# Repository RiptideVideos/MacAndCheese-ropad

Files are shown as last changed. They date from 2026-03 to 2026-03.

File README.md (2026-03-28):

# MacAndCheese-ropad

The MacAndCheese-ropad is a 4x4 macropad running on a Xiao RP2040. All 16 of the macropad buttons are fully customizable with the QMK firmware or other firmware that the RP2040 supports. 

The MacAndCheese-ropad is intended to be used for daily tasks like copying, pasting, taking a screenshot, ect. THe buttons can also be used as extra function buttons (up to 8 on MacOS and 12 on Windows). Using more adanced software, the buttons could be tied to app specific functions or really anything that can be run on a computer.

> Learn more about button use for QMK here: https://docs.qmk.fm/keycodes_basic

I built the MacAndCheese-ropad because I thought it would be a fun but not to hard challage, it has been just as expected. While some of it was smooth sailing a lot was feeling like I was in the dark on many things, however I was able to pull through and continue the project. I hope this macropad makes me more productive and proud to have somthing I worked hard on be usful to me.

## The Design:

The design features 16 square keys layed out in a 4x4 grid.
- The keys are Cherry MX switches.
- There is a empty space right of the keys which holds the Xiao RP2040.

> Onshape File: https://cad.onshape.com/documents/c366476147c6a16a111f20a0/w/74e1df7ada6eec6626497acf/e/e85a476c3b104135c352d93f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
 
Screenshot 2026-03-14 at 8 59 48 AM

## The PCB:

The PCB uses a matrix to support all 16 keys, a photo of the PCB in KiCad is below:

Screenshot 2026-03-20 at 3 21 23 PM

## The Firmware

The MacAndCheese-ropad uses the QMK firmware to give the keys uses, currentally the firmware is set up with 2 layers of keys. (The exact set up is in the repo).

## Bill of Materials

| Item | Qty | Source | Price | Unit Price | Provided by Hackpad? |
|---|-----|---|---|---|---|
| Seeed XIAO RP2040 | 1 | https://www.seeedstudio.com/XIAO-RP2040-v1-0-p-5026.html | $3.99 | $3.99 | Yes |
| 1N4148 Diodes | 16 | https://www.amazon.com/dp/B06XB1R2NK | ~$0.05	| $4.99 | Yes |
| Cherry MX Switches | 16 | https://www.amazon.com/Cherry-Switch-Mechanical-Keyboard-Switches/ | $0.55	| $19.99 | Yes |
| DSA Keycaps | 16 | https://www.amazon.com/Mechkeeb-Profile-Switches-Keyboard-Replacement/dp/B0BWDQ3NKK | ~$0.37 | $8.99 | Yes |
| PCB | 1 | JLC PCB | $4-7 | $4-7 | Via Grant |
| Soldering Iron | 1 | https://pine64.com/product/pinecil-smart-mini-portable-soldering-iron/ | $25.99 | $25.99 | Via Grant |

> Notes on BOM:
> The PCB price changes based on color, settings and deliver option.
> The exact Soldering Iron isn't needed for this project and you could get others online.

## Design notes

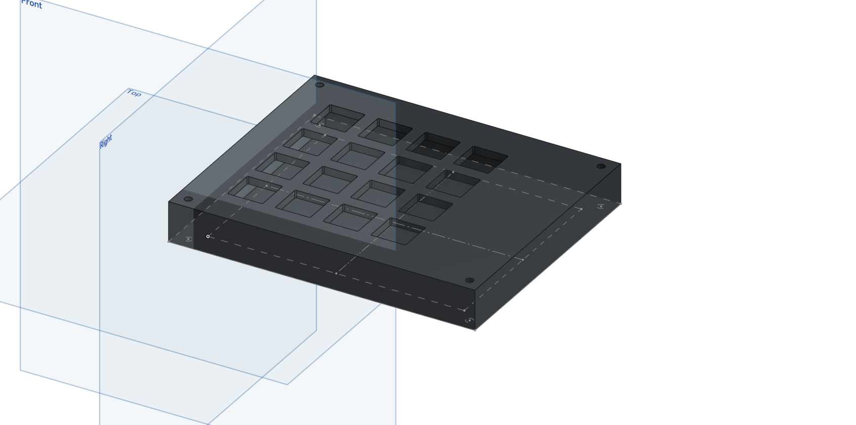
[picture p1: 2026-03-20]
Images/caddesign.png

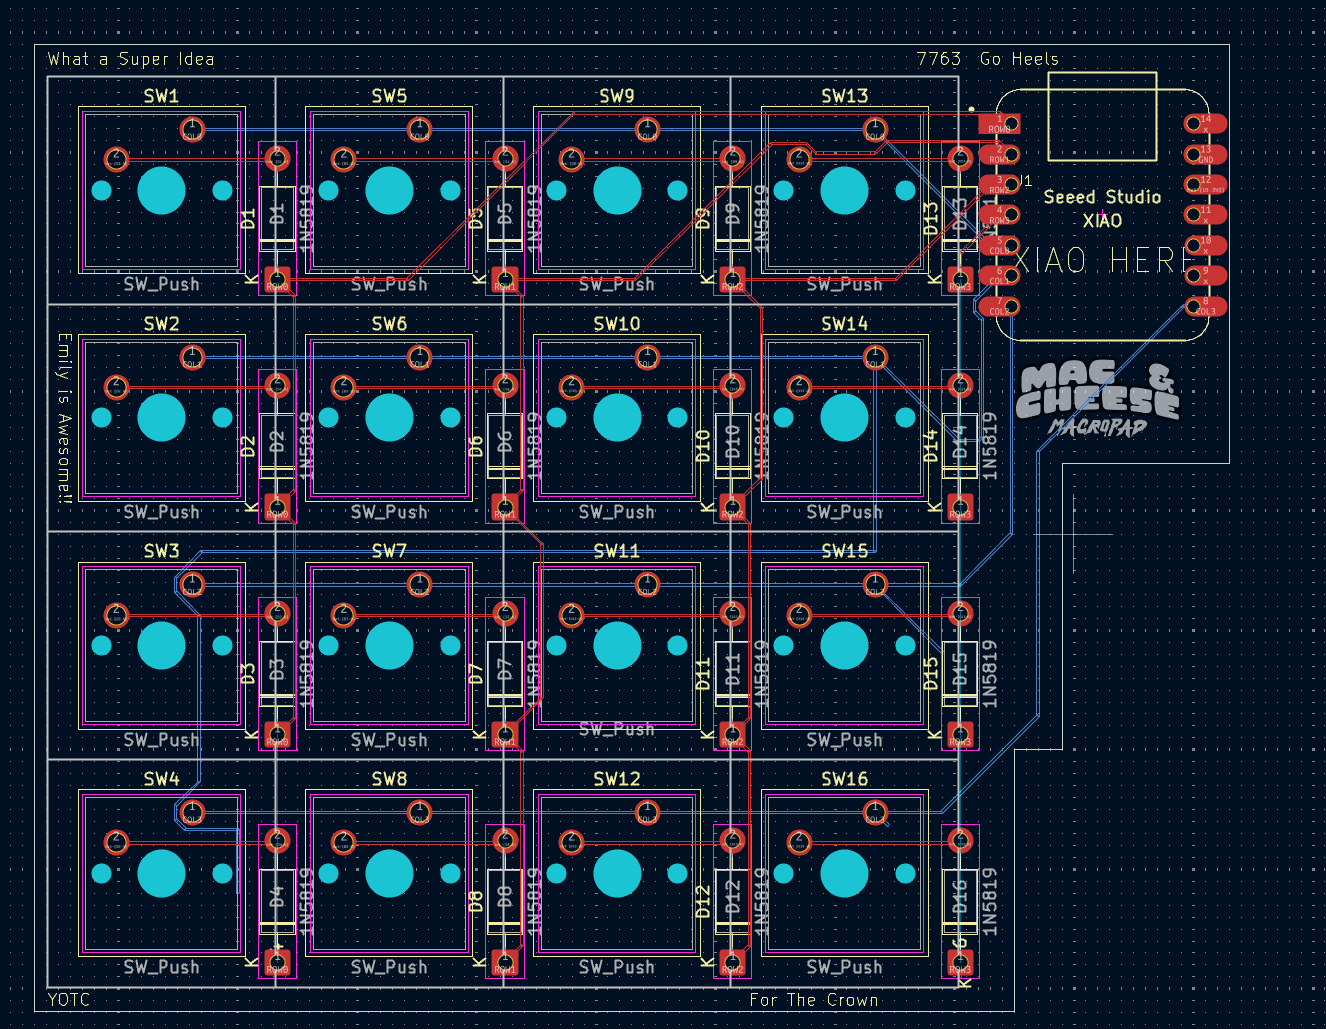
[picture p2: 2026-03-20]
Images/pcb.png

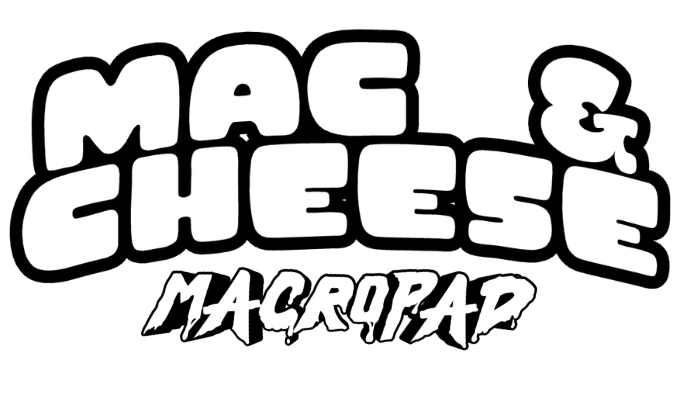
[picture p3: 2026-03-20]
Images/Mac%Cheese-ropad.png

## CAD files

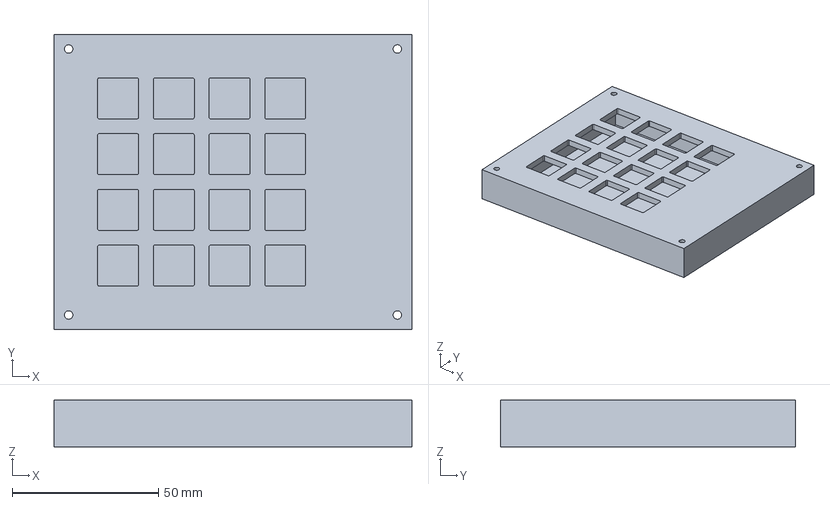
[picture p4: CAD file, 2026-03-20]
3D Files/4x4 PCB 1.step
122.4 x 101.0 x 16.0 mm

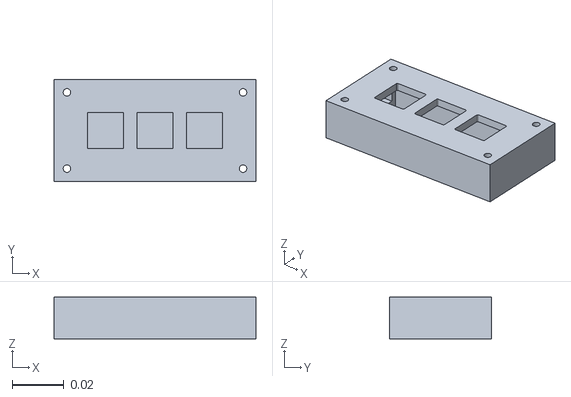
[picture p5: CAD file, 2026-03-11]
3D Files/3x1 PCB.stl
0.0778 x 0.0394 x 0.016

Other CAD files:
3D Files/4x4 PCB 1.stl

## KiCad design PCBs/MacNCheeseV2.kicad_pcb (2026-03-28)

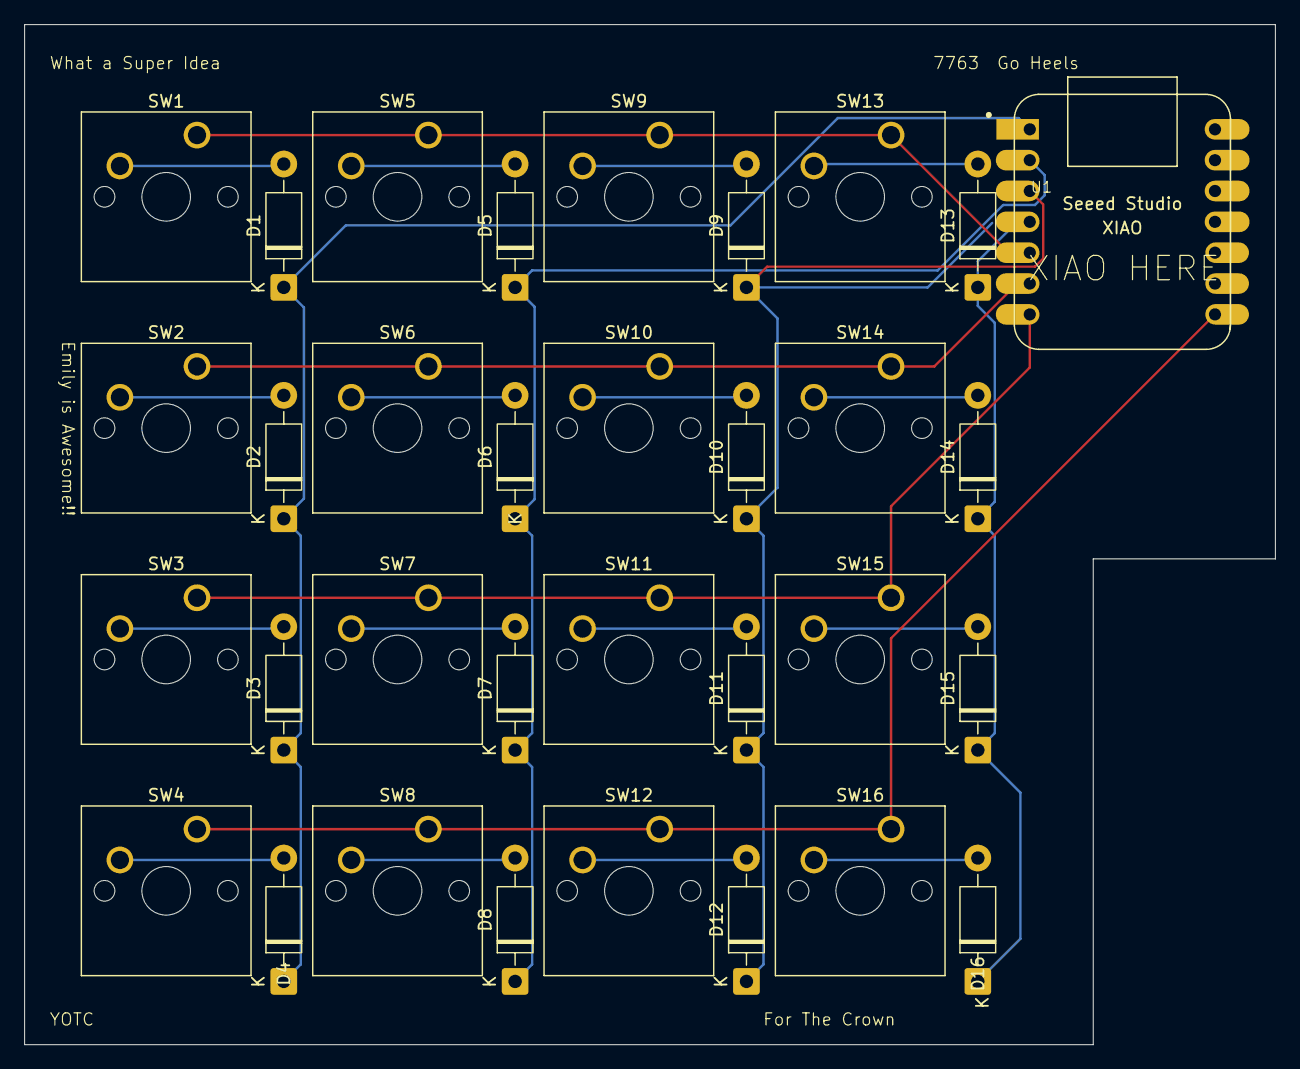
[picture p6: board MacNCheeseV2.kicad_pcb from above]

Board: 2 copper layers, 103.0 x 84.0 mm, 33 parts (0 on the bottom side), 24 nets.

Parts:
D1, D2, D3, D4, D5, D6, D7, D8, D9, D10, D11, D12, D13, D14, D15, D16: 1N5819; D_DO-41_SOD81_P10.16mm_Horizontal
SW1, SW2, SW3, SW4, SW5, SW6, SW7, SW8, SW9, SW10, SW11, SW12, SW13, SW14, SW15, SW16: SW_Push; SW_Cherry_MX_1.00u_PCB
U1: MOUDLE-SEEEDUINO-XIAO; XIAO-Generic-Hybrid-14P-2.54-21X17.8MM

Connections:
/COL0: SW1.1, SW5.1, SW9.1, SW13.1, U1.5 (PA8_A4_D4_SDA)
/COL1: SW2.1, SW6.1, SW10.1, SW14.1, U1.6 (PA9_A5_D5_SCL)
/COL2: SW3.1, SW7.1, SW11.1, SW15.1, U1.7 (PB08_A6_D6_TX)
/COL3: SW4.1, SW8.1, SW12.1, SW16.1, U1.8 (PB09_A7_D7_RX)
/ROW0: D1.1 (K), D2.1 (K), D3.1 (K), D4.1 (K), U1.1 (PA02_A0_D0)
/ROW1: D5.1 (K), D6.1 (K), D7.1 (K), D8.1 (K), U1.2 (PA4_A1_D1)
/ROW2: D9.1 (K), D10.1 (K), D11.1 (K), D12.1 (K), U1.3 (PA10_A2_D2)
/ROW3: D13.1 (K), D14.1 (K), D15.1 (K), D16.1 (K), U1.4 (PA11_A3_D3)
unnamed: D1.2 (A), SW1.2
unnamed: D2.2 (A), SW2.2
unnamed: D3.2 (A), SW3.2
unnamed: D4.2 (A), SW4.2
unnamed: D5.2 (A), SW5.2
unnamed: D6.2 (A), SW6.2
unnamed: D7.2 (A), SW7.2
unnamed: D8.2 (A), SW8.2
unnamed: D9.2 (A), SW9.2
unnamed: D10.2 (A), SW10.2
unnamed: D11.2 (A), SW11.2
unnamed: D12.2 (A), SW12.2
unnamed: D13.2 (A), SW13.2
unnamed: D14.2 (A), SW14.2
unnamed: D15.2 (A), SW15.2
unnamed: D16.2 (A), SW16.2

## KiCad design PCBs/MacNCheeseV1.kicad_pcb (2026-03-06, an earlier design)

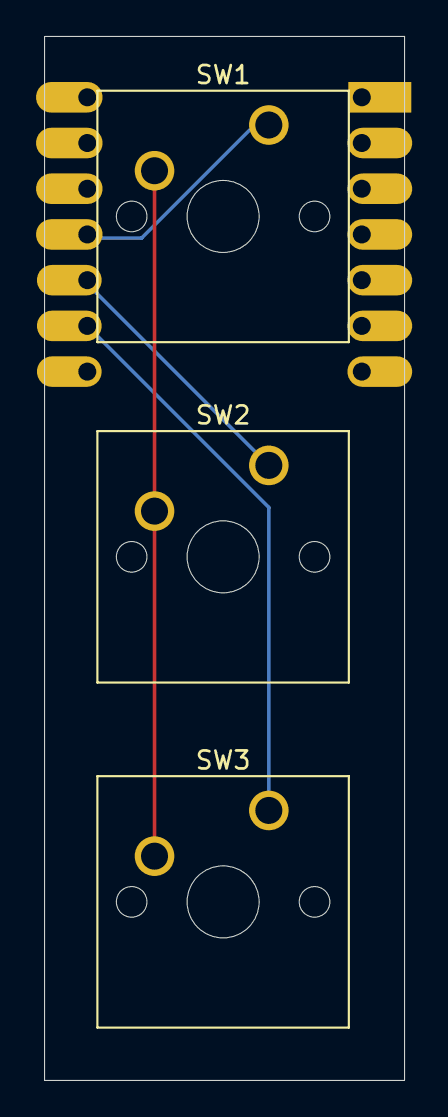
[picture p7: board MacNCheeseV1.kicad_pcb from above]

Board: 2 copper layers, 20.0 x 58.0 mm, 4 parts (1 on the bottom side), 4 nets.

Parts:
SW1, SW2, SW3: SW_Push; SW_Cherry_MX_1.00u_PCB
U1: MOUDLE-SEEEDUINO-XIAO; XIAO-Generic-Hybrid-14P-2.54-21X17.8MM

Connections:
GND: SW1.2, SW2.2, SW3.2, U1.13 (GND)
unnamed: SW2.1, U1.10 (PA5_A9_D9_MISO)
unnamed: SW1.1, U1.11 (PA6_A10_D10_MOSI)
unnamed: SW3.1, U1.9 (PA7_A8_D8_SCK)

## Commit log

2026-03-06 PCB V1
    Basic design from the guide
    [MacNCheeseV1.kicad_pcb]
2026-03-06 PCB V1
    [MacNCheeseV1.kicad_pcb]
2026-03-11 Test of 3x1 Design
    [3x1 PCB.stl]
2026-03-15 PCBs V2.1
    Added Designs
    [MacNCheeseV2.kicad_pcb]
2026-03-20 PCB V2.2
    Slight design changes to make in <100mm
    [MacNCheeseV2.kicad_pcb]
2026-03-20 4x4 V1 STEP
    [4x4 PCB 1.step]
